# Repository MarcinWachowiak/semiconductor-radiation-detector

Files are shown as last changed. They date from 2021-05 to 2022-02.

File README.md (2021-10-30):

# Semiconductor Radiation Detector
<div align="justify">
Radiation detector based on PIN diode with extensive signal processing. The signal chain consists of multiple stages such as bootstrapped preamplifier, filtering, baseline restorer, sample and hold, and set of comparators detecting slopes of pulses. The signal processing board provides analog output for ADC along with digital signals triggering measurements. <a href="https://hackaday.io/project/159909-gamma-pin-semiconductor-radiation-detector">Hackaday project log</a>

</div>

  - **Manufactured prototypes**
  
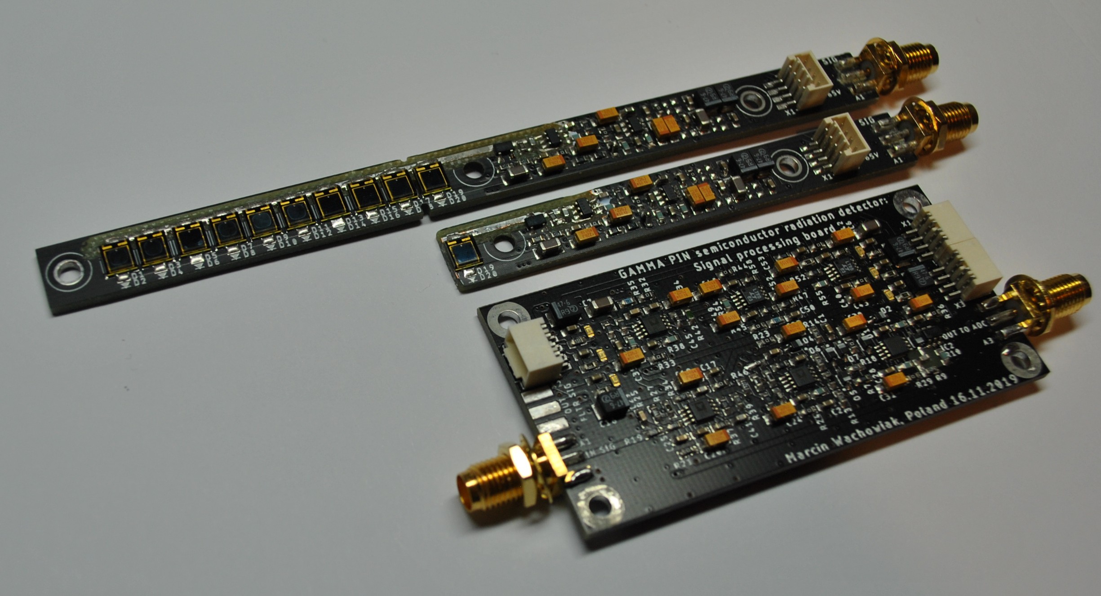
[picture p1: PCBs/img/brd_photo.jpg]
board_photo
    

  - **Preamplifier board**

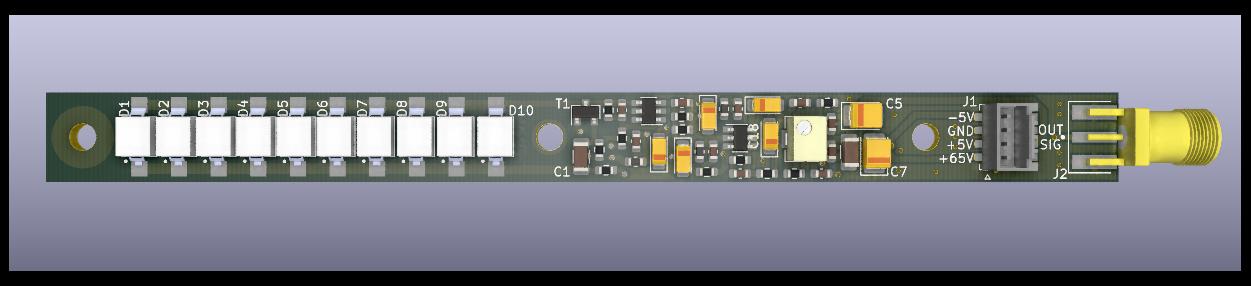
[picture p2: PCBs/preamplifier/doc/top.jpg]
preamplifier_top
    
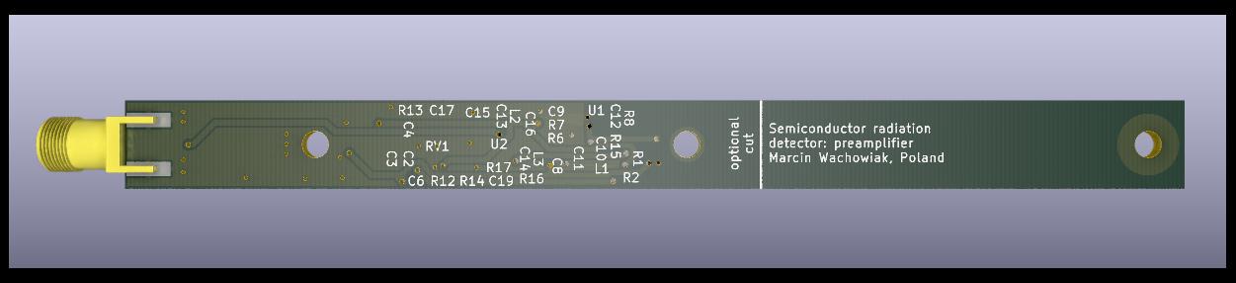
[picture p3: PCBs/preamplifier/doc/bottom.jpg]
preamplifier_bottom
    

  - **Signal processing board**

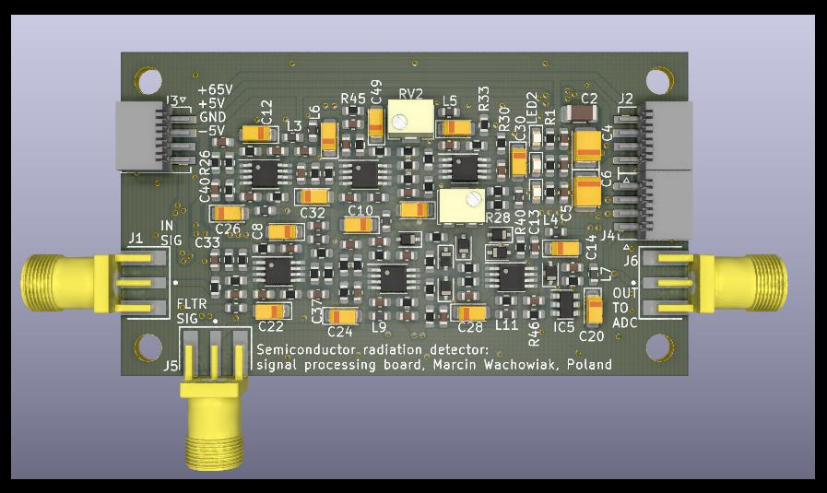
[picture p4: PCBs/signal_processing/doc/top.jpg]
signal_processing_top
    
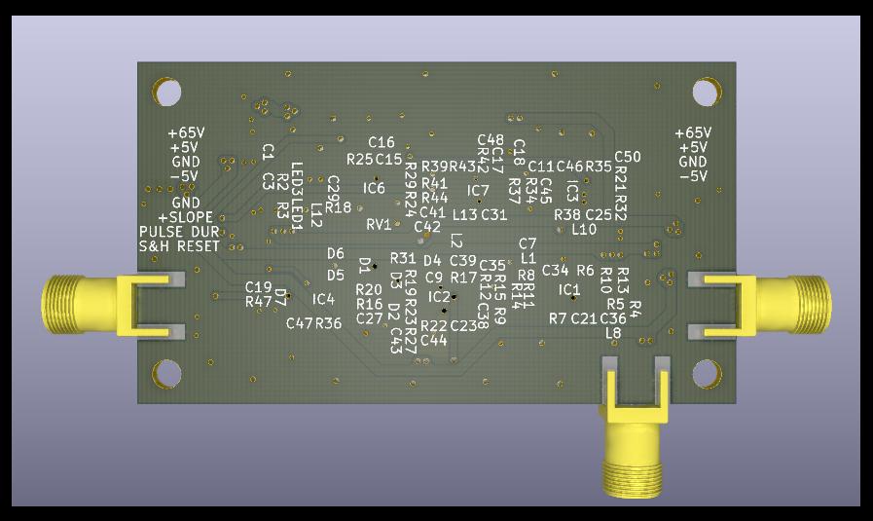
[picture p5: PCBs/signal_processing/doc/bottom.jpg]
signal_processing_bottom


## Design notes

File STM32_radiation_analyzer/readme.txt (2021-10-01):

In case of problems with COM port opening, either use Teraterm instead of Putty or try to modify usb_cdc
according to https://github.com/Ant1882/STM32F429-Tracealyzer-Demo/commit/4cf6591b3bdff098292349874f8c0c8df7802986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
this issue is encountered mostly on Win 10.

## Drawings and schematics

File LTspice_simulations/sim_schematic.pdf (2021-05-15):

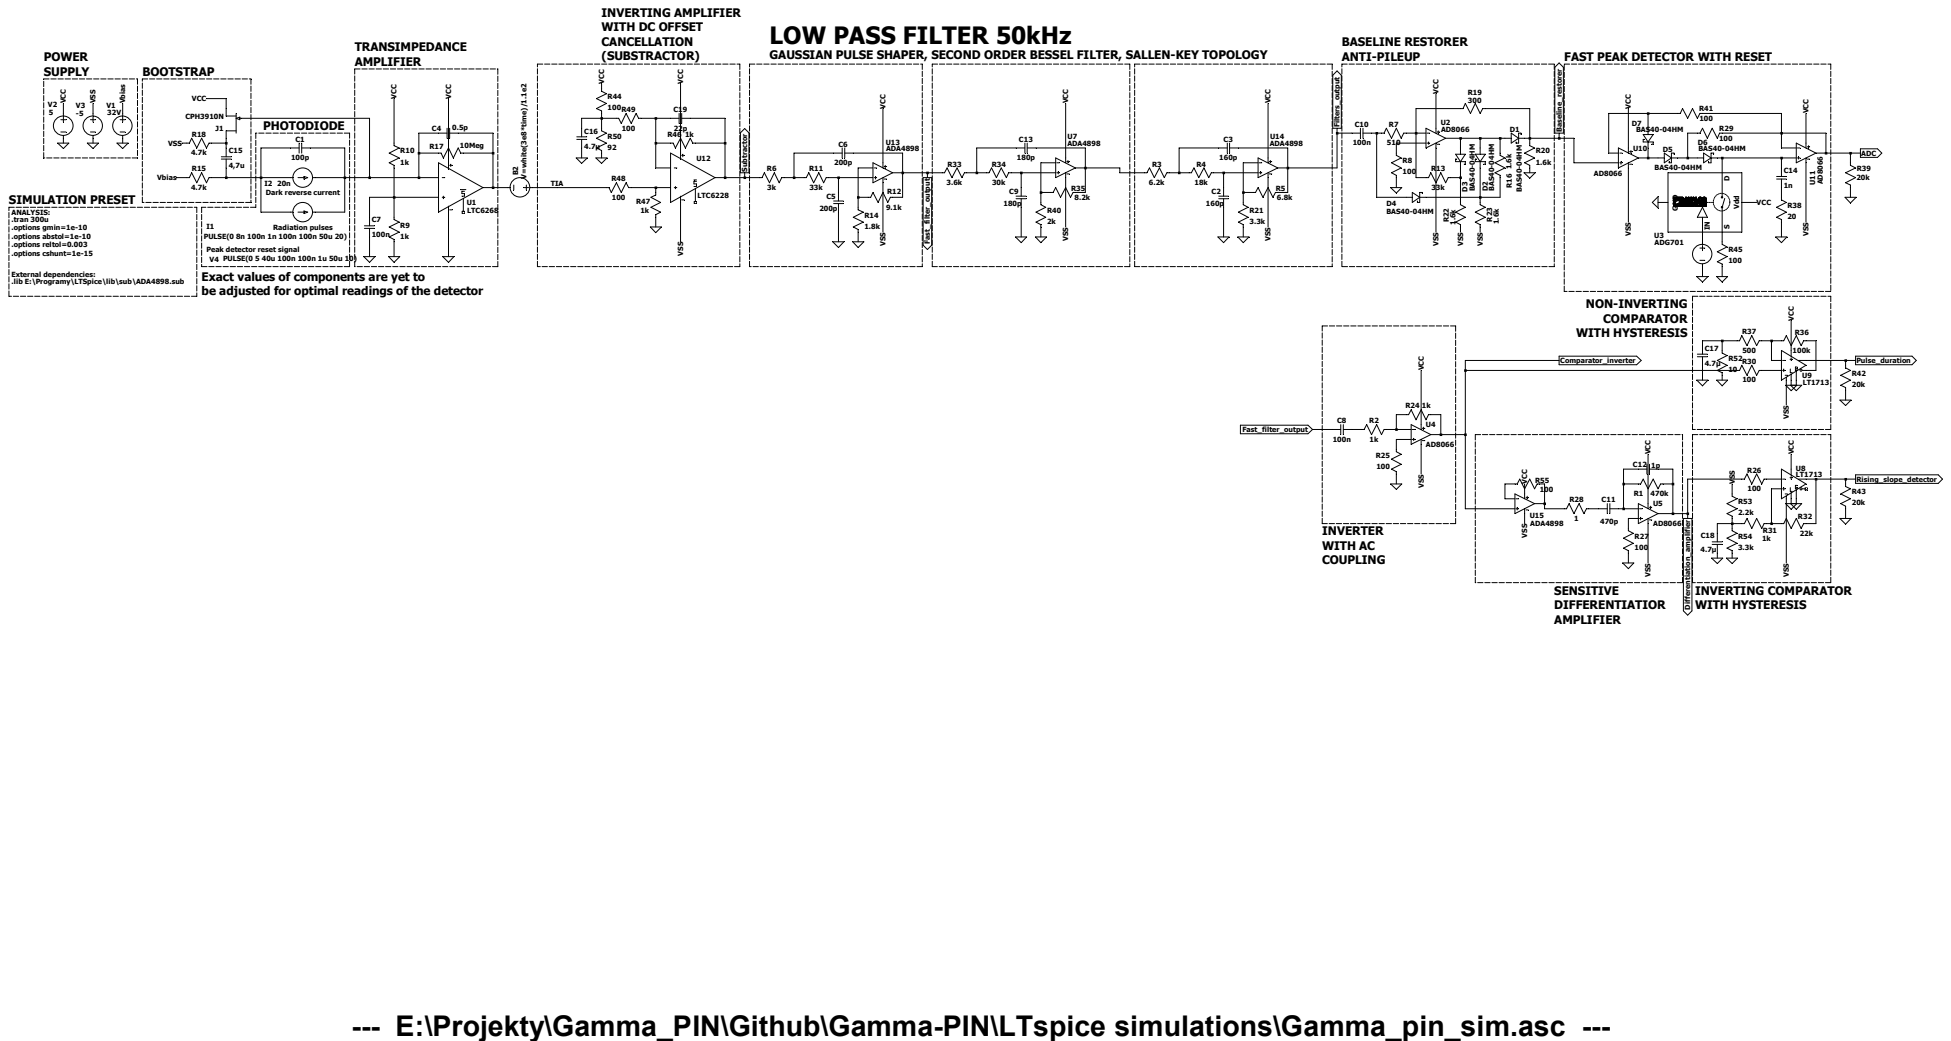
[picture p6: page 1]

LOW PASS FILTER 50kHz
GAUSSIAN PULSE SHAPER, SECOND ORDER BESSEL FILTER, SALLEN-KEY TOPOLOGY

FAST PEAK DETECTOR WITH RESET

PULSE(0 8n 100n 1n 100n 100n 50u 20)
Peak detector reset signal
V4 PULSE(0 5 40u 100n 100n 1u 50u 10)
Exact values of components are yet to
be adjusted for optimal readings of the detector

External dependencies:
.lib E:\Programy\LTSpice\lib\sub\ADA4898.sub

--- E:\Projekty\Gamma_PIN\Github\Gamma-PIN\LTspice simulations\Gamma_pin_sim.asc ---

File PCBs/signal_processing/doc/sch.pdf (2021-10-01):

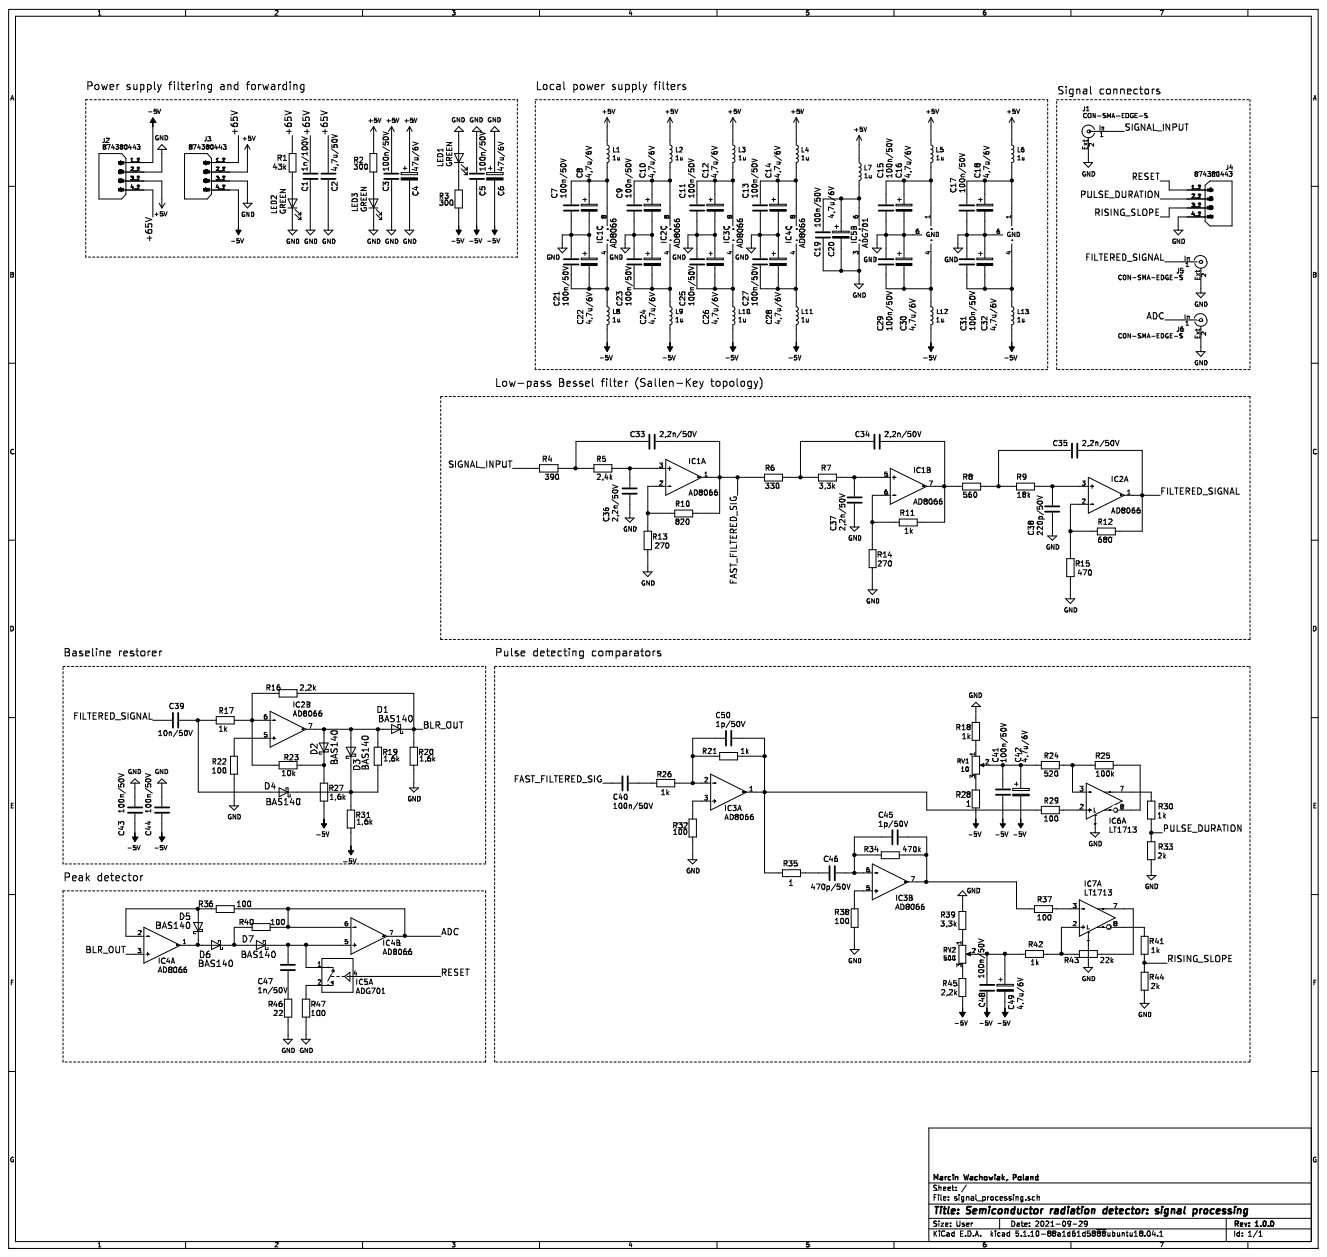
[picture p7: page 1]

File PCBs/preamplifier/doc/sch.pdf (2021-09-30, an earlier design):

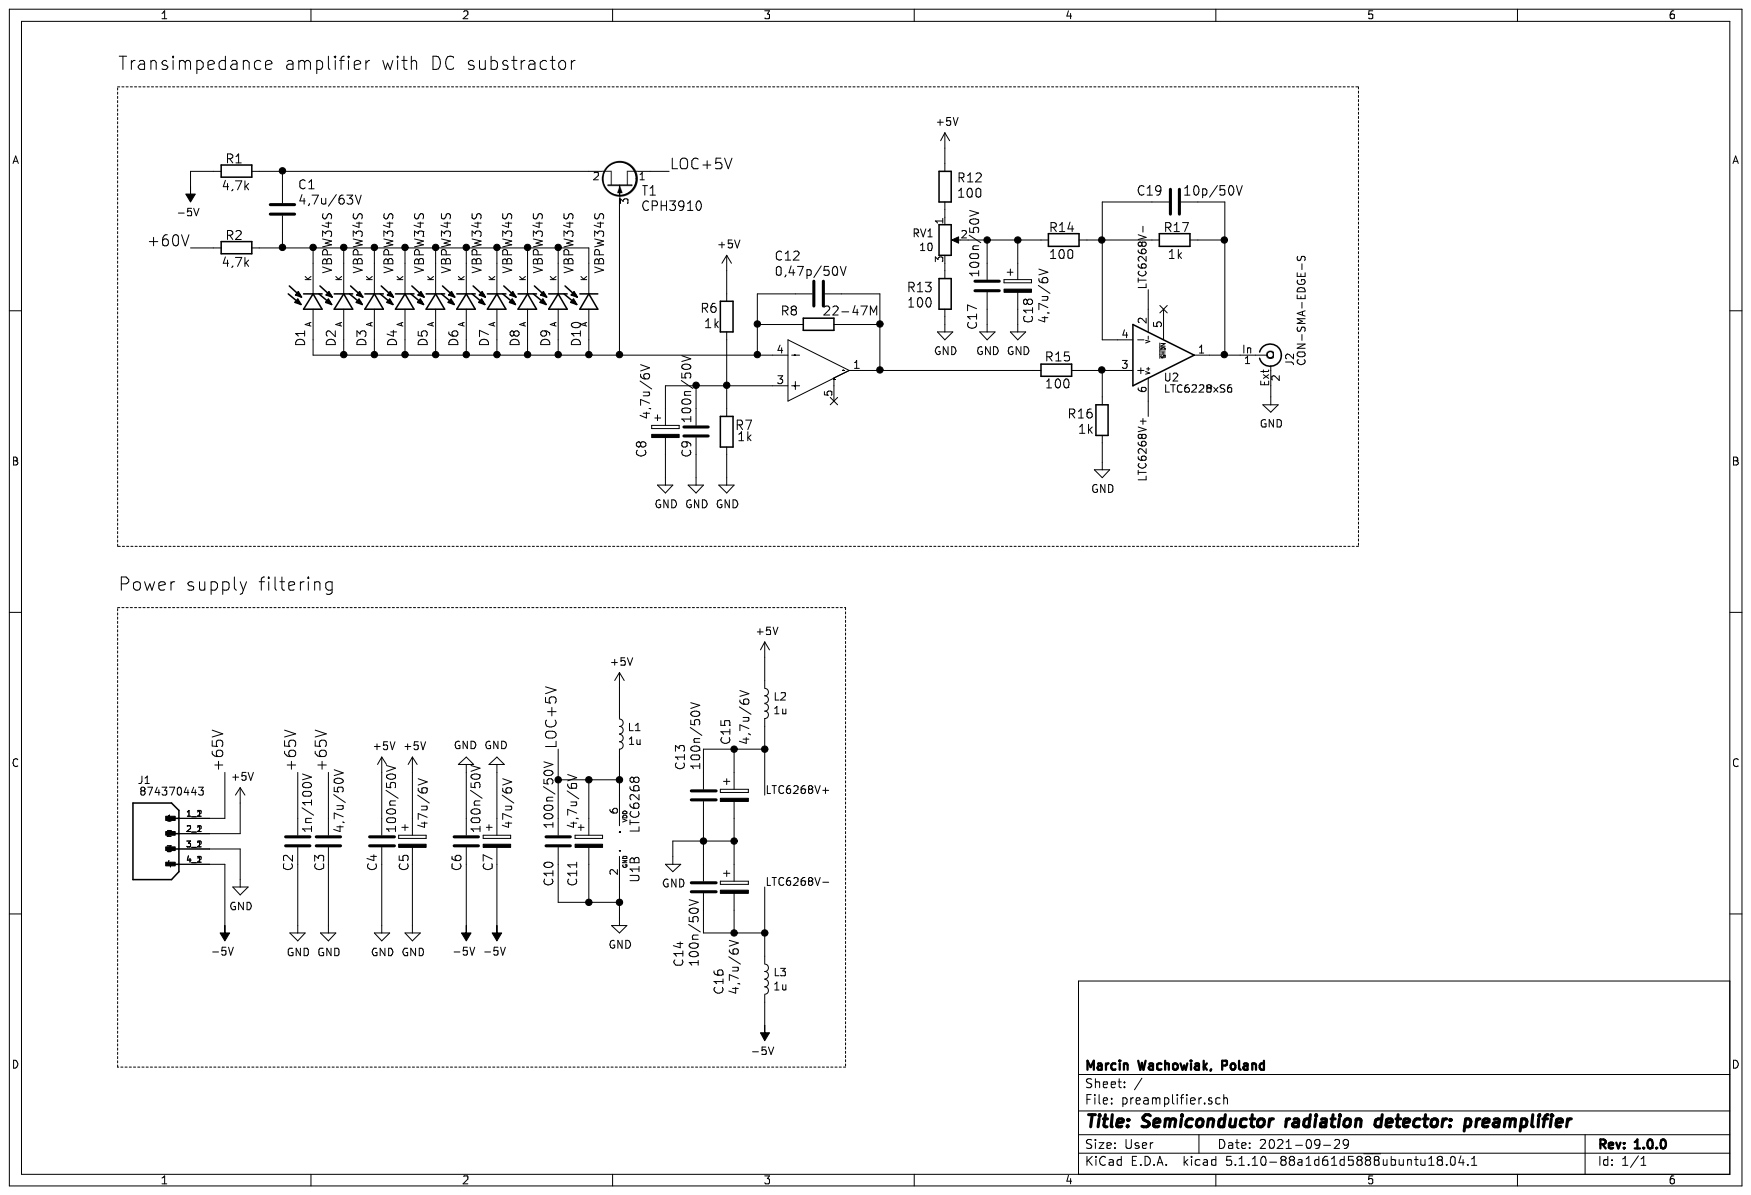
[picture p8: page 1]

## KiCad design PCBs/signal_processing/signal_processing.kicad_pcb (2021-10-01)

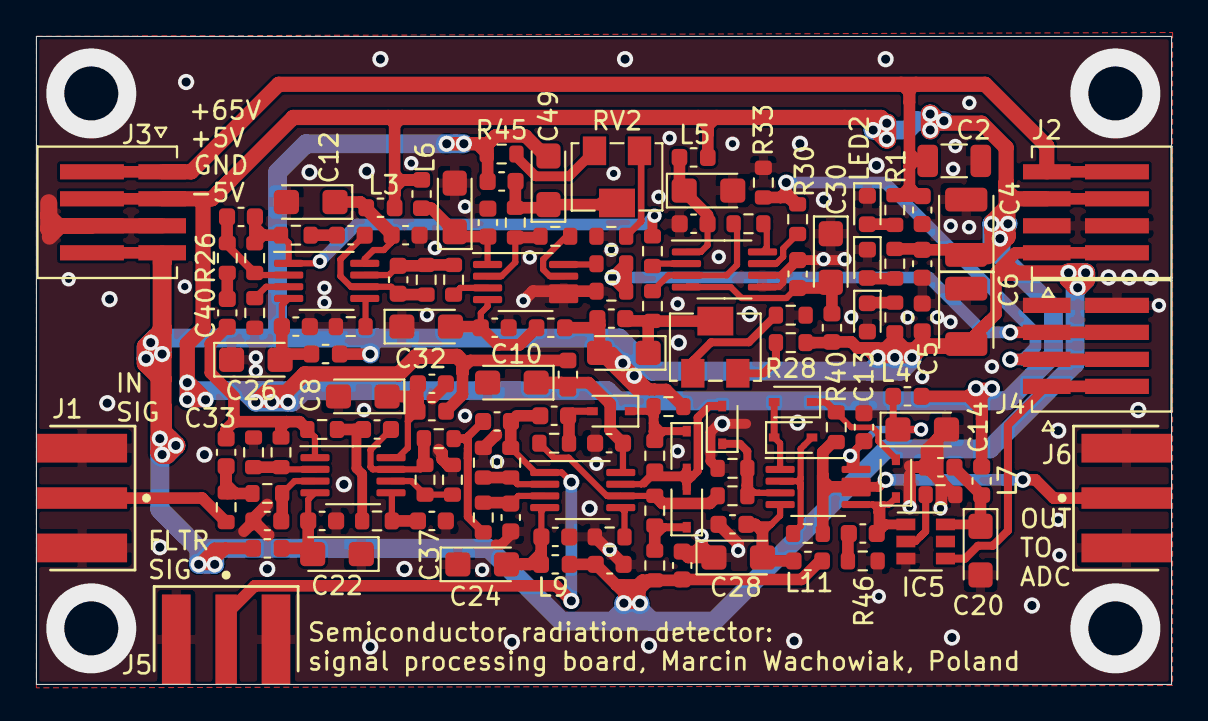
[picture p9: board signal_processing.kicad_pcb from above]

Board: 2 copper layers, 63.1 x 36.0 mm, 135 parts (0 on the bottom side), 72 nets.

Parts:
C1: 1n/100V; C_0603_1608Metric
C2: 4,7u/50V; C_1206_3216Metric
C3, C5, C7, C9, C11, C13, C15, C17, C19, C21, C23, C25, C27, C29, C31, C40, C41, C43, C44, C48: 100n/50V; C_0603_1608Metric
C4, C6: 47u/6V; CP_EIA-3528-21_Kemet-B
C8, C10, C12, C14, C16, C18, C20, C22, C24, C26, C28, C30, C32, C42, C49: 4,7u/6V; CP_EIA-3216-18_Kemet-A
C33, C34, C35, C36, C37: 2,2n/50V; C_0603_1608Metric
C38: 220p/50V; C_0603_1608Metric
C39: 10n/50V; C_0603_1608Metric
C45, C50: 1p/50V; C_0603_1608Metric
C46: 470p/50V; C_0603_1608Metric
C47: 1n/50V; C_0603_1608Metric
D1, D2, D3, D4, D5, D6, D7: BAS140; D_SOD-323
IC1, IC2, IC3, IC4: AD8066; MSOP-8_3x3mm_P0.65mm
IC5: ADG701; SOT-23-6
IC6, IC7: LT1713; MSOP-8_3x3mm_P0.65mm
J1, J5, J6: CON-SMA-EDGE-S
J2, J3, J4: 874380443; 87438-0443
L1, L2, L3, L4, L5, L6, L7, L8, L9, L10, L11, L12, L13: 1u; L_0603_1608Metric
LED1, LED2, LED3: GREEN; LED_0603_1608Metric
R1: 43k; R_0603_1608Metric
R2, R3: 300; R_0603_1608Metric
R4: 390; R_0603_1608Metric
R5: 2,4k; R_0603_1608Metric
R6: 330; R_0603_1608Metric
R7, R39: 3,3k; R_0603_1608Metric
R8: 560; R_0603_1608Metric
R9: 18k; R_0603_1608Metric
R10: 820; R_0603_1608Metric
R11, R17, R18, R21, R26, R30, R41, R42: 1k; R_0603_1608Metric
R12: 680; R_0603_1608Metric
R13, R14: 270; R_0603_1608Metric
R15: 470; R_0603_1608Metric
R16, R45: 2,2k; R_0603_1608Metric
R19, R20, R27, R31: 1,6k; R_0603_1608Metric
R22, R29, R32, R36, R37, R38, R40, R47: 100; R_0603_1608Metric
R23: 10k; R_0603_1608Metric
R24: 520; R_0603_1608Metric
R25: 100k; R_0603_1608Metric
R28, R35: 1; R_0603_1608Metric
R33, R44: 2k; R_0603_1608Metric
R34: 470k; R_0603_1608Metric
R43: 22k; R_0603_1608Metric
R46: 22; R_0603_1608Metric
RV1: 10; Potentiometer_Bourns_3224W_Vertical
RV2: 500; Potentiometer_Bourns_3224W_Vertical

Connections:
+5V: C3.2, C4.1, J2.3_1, J2.3_2, J3.2_1, J3.2_2, L1.1, L2.1, L3.1, L4.1, L5.1, L6.1, L7.1, R2.1
-5V: C5.1, C6.2, C41.2, C42.2, C43.1, C44.1, C48.2, C49.2, J2.1_1, J2.1_2, J3.4_1, J3.4_2, L8.2, L9.2, L10.2, L11.2, L12.2, L13.2, R3.2, R27.1, R28.1, R31.1, R45.1
/+65V: C1.2, C2.1, J2.4_1, J2.4_2, J3.1_1, J3.1_2, R1.1
/ADC: IC4.6, IC4.7, J6.1, R36.1, R40.1
/BLR_OUT: D1.1, IC4.3, R16.2, R20.2
/FAST_FILTERED_SIG: C33.1, C40.2, IC1.1, R6.2, R10.1
/FILTERED_SIGNAL: C35.1, C39.2, IC2.1, J5.1, R12.1
/PULSE_DURATION: J4.2_1, J4.2_2, R30.2, R33.1
/RESET: IC5.4, J4.1_1, J4.1_2
/RISING_SLOPE: J4.3_1, J4.3_2, R41.2, R44.1
/SIGNAL_INPUT: J1.1, R4.2
GND: C1.1, C2.2, C3.1, C4.2, C5.2, C6.1, C7.1, C8.2, C9.1, C10.2, C11.1, C12.2, C13.1, C14.2, C15.1, C16.2, C17.1, C18.2, C19.1, C20.2, C21.2, C22.1, C23.2, C24.1, C25.2, C26.1, C27.2, C28.1, C29.2, C30.1, C31.2, C32.1, C36.1, C37.1, C38.1, C43.2, C44.2, IC5.3, IC6.5, IC6.6, IC7.5, IC7.6, J1.2, J2.2_1, J2.2_2, J3.3_1, J3.3_2, J4.4_1, J4.4_2, J5.2, J6.2, LED1.2, LED2.1, LED3.1, R13.2, R14.2, R15.2, R18.2, R20.1, R22.2, R32.2, R33.2, R38.2, R39.2, R44.2, R46.2, R47.2
unnamed: C7.2, C8.1, IC1.8, L1.2
unnamed: C9.2, C10.1, IC2.8, L2.2
unnamed: C11.2, C12.1, IC3.8, L3.2
unnamed: C13.2, C14.1, IC4.8, L4.2
unnamed: C15.2, C16.1, IC6.1, L5.2
unnamed: C17.2, C18.1, IC7.1, L6.2
unnamed: C19.2, C20.1, IC5.6, L7.2
unnamed: C21.1, C22.2, IC1.4, L8.1
unnamed: C23.1, C24.2, IC2.4, L9.1
unnamed: C25.1, C26.2, IC3.4, L10.1
unnamed: C27.1, C28.2, IC4.4, L11.1
unnamed: C29.1, C30.2, IC6.4, L12.1
unnamed: C31.1, C32.2, IC7.4, L13.1
unnamed: C33.2, R4.1, R5.2
unnamed: C34.1, IC1.7, R8.2, R11.1
unnamed: C34.2, R6.1, R7.2
unnamed: C35.2, R8.1, R9.2
unnamed: C36.2, IC1.3, R5.1
unnamed: C37.2, IC1.5, R7.1
unnamed: C38.2, IC2.3, R9.1
unnamed: C39.1, D4.2, R17.2
unnamed: C40.1, R26.1
unnamed: C41.1, C42.1, R24.2, RV1.2
unnamed: C45.1, IC3.7, R34.1, R37.2
unnamed: C45.2, C46.1, IC3.6, R34.2
unnamed: C46.2, R35.1
unnamed: C47.1, D7.1, IC4.5, IC5.1
unnamed: C47.2, R46.1
unnamed: C48.1, C49.1, R42.2, RV2.2
unnamed: C50.1, IC3.1, R21.1, R29.2, R35.2
unnamed: C50.2, IC3.2, R21.2, R26.2
unnamed: D1.2, D2.2, D3.2, IC2.7, R19.2
unnamed: D2.1, R23.2, R27.2
unnamed: D3.1, D4.1, R19.1, R31.2
unnamed: D5.1, D6.2, IC4.1
unnamed: D5.2, IC4.2, R36.2
unnamed: D6.1, D7.2, R40.2
unnamed: IC1.2, R10.2, R13.1
unnamed: IC1.6, R11.2, R14.1
unnamed: IC2.2, R12.2, R15.1
unnamed: IC2.5, R22.1
unnamed: IC2.6, R16.1, R17.1, R23.1
unnamed: IC3.3, R32.1
unnamed: IC3.5, R38.1
unnamed: IC5.2, R47.1
unnamed: IC6.2, R29.1
unnamed: IC6.3, R24.1, R25.2
unnamed: IC6.7, R30.1
unnamed: IC6.8, R25.1
unnamed: IC7.2, R42.1, R43.2
unnamed: IC7.3, R37.1
unnamed: IC7.7, R43.1
unnamed: IC7.8, R41.1
unnamed: LED1.1, R3.1
unnamed: LED2.2, R1.2
unnamed: LED3.2, R2.2
unnamed: R18.1, RV1.1
unnamed: R28.2, RV1.3
unnamed: R39.1, RV2.1
unnamed: R45.2, RV2.3

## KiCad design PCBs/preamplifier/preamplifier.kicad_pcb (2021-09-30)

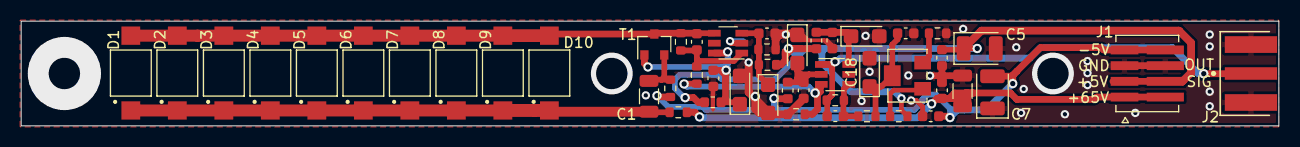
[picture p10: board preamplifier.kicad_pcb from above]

Board: 2 copper layers, 120.2 x 10.0 mm, 49 parts (0 on the bottom side), 18 nets.

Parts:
C1: 4,7u/63V; C_1206_3216Metric
C2: 1n/100V; C_0603_1608Metric
C3: 4,7u/50V; C_1206_3216Metric
C4, C6, C9, C10, C13, C14, C17: 100n/50V; C_0603_1608Metric
C5, C7: 47u/6V; CP_EIA-3528-21_Kemet-B
C8, C11, C15, C16, C18: 4,7u/6V; CP_EIA-3216-18_Kemet-A
C12: 0,47p/50V; C_0603_1608Metric
C19: 10p/50V; C_0603_1608Metric
D1, D2, D3, D4, D5, D6, D7, D8, D9, D10: VBPW34S; XDCR_VBPW34S
J1: 874370443; 87437-0443
J2: CON-SMA-EDGE-S
L1, L2, L3: 1u; L_0603_1608Metric
R1, R2: 4,7k; R_0603_1608Metric
R6, R7, R16, R17: 1k; R_0603_1608Metric
R8: 22-47M; R_0603_1608Metric
R12, R13, R14, R15: 100; R_0603_1608Metric
RV1: 10; Potentiometer_Bourns_3224W_Vertical
T1: CPH3910; SOT-23
U1: LTC6268; TSOT-23-6
U2: LTC6228xS6; TSOT-23-6

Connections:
+5V: C4.2, C5.1, J1.2_1, J1.2_2, L1.1, L2.1, R6.1, R12.1
-5V: C6.1, C7.2, J1.4_1, J1.4_2, L3.2, R1.2
/+60V: C2.2, C3.1, J1.1_1, J1.1_2, R2.2
/LOC+5V: C10.2, C11.1, L1.2, T1.1, U1.6
/LTC6268V+: C13.2, C15.1, L2.2, U2.6
/LTC6268V-: C14.1, C16.2, L3.1, U2.2
GND: C2.1, C3.2, C4.1, C5.2, C6.2, C7.1, C8.2, C9.1, C10.1, C11.2, C13.1, C14.2, C15.2, C16.1, C17.2, C18.2, J1.3_1, J1.3_2, J2.2, R7.2, R13.2, R16.2, U1.2
unnamed: C1.1, D1.K, D2.K, D3.K, D4.K, D5.K, D6.K, D7.K, D8.K, D9.K, D10.K, R2.1
unnamed: C1.2, R1.1, T1.2
unnamed: C8.1, C9.2, R6.2, R7.1, U1.3
unnamed: C12.1, R8.2, R15.1, U1.1
unnamed: C12.2, D1.A, D2.A, D3.A, D4.A, D5.A, D6.A, D7.A, D8.A, D9.A, D10.A, R8.1, T1.3, U1.4
unnamed: C17.1, C18.1, R14.2, RV1.2
unnamed: C19.1, R14.1, R17.2, U2.4
unnamed: C19.2, J2.1, R17.1, U2.1
unnamed: R12.2, RV1.1
unnamed: R13.1, RV1.3
unnamed: R15.2, R16.1, U2.3

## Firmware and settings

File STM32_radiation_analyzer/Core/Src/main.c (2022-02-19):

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
/* Includes ------------------------------------------------------------------*/
#include "main.h"
#include "string.h"
#include "usb_device.h"

/* USER CODE BEGIN Includes */
#include "usbd_cdc_if.h"
#include "string.h"
/* USER CODE END Includes */

/* USER CODE BEGIN PD */

//number of ADC samples to average (16bit samples to save)
#define ADC_BUF_LEN 10

/* USER CODE END PD */

#if defined ( __ICCARM__ ) /*!< IAR Compiler */

#pragma location=0x30040000
ETH_DMADescTypeDef  DMARxDscrTab[ETH_RX_DESC_CNT]; /* Ethernet Rx DMA Descriptors */
#pragma location=0x30040060
ETH_DMADescTypeDef  DMATxDscrTab[ETH_TX_DESC_CNT]; /* Ethernet Tx DMA Descriptors */
#pragma location=0x300400c0
uint8_t Rx_Buff[ETH_RX_DESC_CNT][ETH_MAX_PACKET_SIZE]; /* Ethernet Receive Buffers */

#elif defined ( __CC_ARM )  /* MDK ARM Compiler */

__attribute__((at(0x30040000))) ETH_DMADescTypeDef  DMARxDscrTab[ETH_RX_DESC_CNT]; /* Ethernet Rx DMA Descriptors */
__attribute__((at(0x30040060))) ETH_DMADescTypeDef  DMATxDscrTab[ETH_TX_DESC_CNT]; /* Ethernet Tx DMA Descriptors */
__attribute__((at(0x300400c0))) uint8_t Rx_Buff[ETH_RX_DESC_CNT][ETH_MAX_PACKET_SIZE]; /* Ethernet Receive Buffer */

#elif defined ( __GNUC__ ) /* GNU Compiler */

ETH_DMADescTypeDef DMARxDscrTab[ETH_RX_DESC_CNT] __attribute__((section(".RxDecripSection"))); /* Ethernet Rx DMA Descriptors */
ETH_DMADescTypeDef DMATxDscrTab[ETH_TX_DESC_CNT] __attribute__((section(".TxDecripSection")));   /* Ethernet Tx DMA Descriptors */
uint8_t Rx_Buff[ETH_RX_DESC_CNT][ETH_MAX_PACKET_SIZE] __attribute__((section(".RxArraySection"))); /* Ethernet Receive Buffers */

#endif

ETH_TxPacketConfig TxConfig;
ADC_HandleTypeDef hadc1;
DMA_HandleTypeDef hdma_adc1;

ETH_HandleTypeDef heth;

RTC_HandleTypeDef hrtc;

TIM_HandleTypeDef htim16;

void SystemClock_Config(void);
static void MX_GPIO_Init(void);
static void MX_DMA_Init(void);
static void MX_ETH_Init(void);
static void MX_ADC1_Init(void);
static void MX_TIM16_Init(void);
static void MX_RTC_Init(void);
/* USER CODE BEGIN 0 */
static uint16_t adc_dma_buf [ADC_BUF_LEN];
static uint16_t pulse_ampl_cnt_arr [4096] = {0};
static uint32_t pulse_cnt = 0;

static uint32_t time_cnt = 0;
static uint32_t rising_slope_cnt = 0;

uint8_t conv_cplt = 0;

/* USER CODE END 0 */

/**
  * @brief  The application entry point.
  * @retval int
  */
int main(void)
{
  /* MCU Configuration--------------------------------------------------------*/

  /* Reset of all peripherals, Initializes the Flash interface and the Systick. */
  HAL_Init();

  /* Configure the system clock */
  SystemClock_Config();

  /* Initialize all configured peripherals */
  MX_GPIO_Init();
  MX_DMA_Init();
  MX_ETH_Init();
  MX_ADC1_Init();
  MX_TIM16_Init();
  MX_RTC_Init();
  MX_USB_DEVICE_Init();
  /* USER CODE BEGIN 2 */

  //Start timer
  HAL_TIM_Base_Start_IT(&htim16);

  //ADC calibration
  if(HAL_OK != HAL_ADCEx_Calibration_Start(&hadc1,ADC_CALIB_OFFSET_LINEARITY,ADC_SINGLE_ENDED) && HAL_ADCEx_Calibration_Start(&hadc1,ADC_CALIB_OFFSET,ADC_SINGLE_ENDED)){
	  Error_Handler();
  }

  //start ADC DMA
  if(HAL_OK != HAL_ADC_Start_DMA(&hadc1, (uint32_t*)adc_dma_buf, ADC_BUF_LEN)){
	  Error_Handler();
  }

  // Initialize spectral array to zeros
  memset(pulse_ampl_cnt_arr, 0, sizeof(pulse_ampl_cnt_arr));

  //init message
  HAL_Delay(1000);
  uint8_t buffer[] = "Radiation Analyzer init!\r\n";
  CDC_Transmit_FS(buffer, sizeof(buffer));
  /* USER CODE END 2 */

  /* Infinite loop */
  /* USER CODE BEGIN WHILE */
  while (1)
  {
	    // simple led signal that program is working
		HAL_GPIO_WritePin(GPIOB, GPIO_PIN_14, SET);
		HAL_Delay(1000);
	    //
	    // INTERRUPTS ARE NOT A GOOD PLACE TO DO SEND DATA OR PRINT!
	    //
		HAL_GPIO_WritePin(GPIOB, GPIO_PIN_14, RESET);
		HAL_Delay(1000);
		//GPIOC->ODR = 1 << 3;
		//GPIOC->ODR = 0;

		// TODO add collected data printing to UART
		//	uint8_t buffer2[128];
		//	sprintf(buffer2, "ADC: %d %d %d %d %d %d %d %d %d %d\n\r", adc_dma_buf[0],adc_dma_buf[1],adc_dma_buf[2],adc_dma_buf[3],adc_dma_buf[4],adc_dma_buf[5],adc_dma_buf[6],adc_dma_buf[7],adc_dma_buf[8],adc_dma_buf[9]);
		//	CDC_Transmit_FS(buffer2, sizeof(buffer2));

    /* USER CODE END WHILE */

    /* USER CODE BEGIN 3 */
  }
  /* USER CODE END 3 */
}

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
/* USER CODE BEGIN 4 */

void HAL_TIM_PeriodElapsedCallback(TIM_HandleTypeDef *htim)
{
	if(htim == &htim16){
		  HAL_GPIO_TogglePin(GPIOB, GPIO_PIN_7);
		  time_cnt++;
		  static uint8_t sec_buffer[] = "One second elapsed!\r\n";
		  CDC_Transmit_FS(sec_buffer, sizeof(sec_buffer));
		  if(time_cnt%60 == 0) {
			    static uint8_t min_buffer[] = "One minute elapsed!\r\n";
			    CDC_Transmit_FS(min_buffer, sizeof(min_buffer));
		  	  }
	}
}

//ADC DMA CONVERSION COMPLETE INTERRUPT
void HAL_ADC_ConvCpltCallback(ADC_HandleTypeDef* hadc)
{
	conv_cplt = 1;

	// average collected samples
	uint32_t tmp_sum = 0;
	for (uint8_t i = 0; i < ADC_BUF_LEN; ++i) {
		tmp_sum += adc_dma_buf[i];
	    }
	uint16_t avg_sample_val =(uint16_t) (tmp_sum / ADC_BUF_LEN);

	// increment index corresponding to registered amplitude
	pulse_ampl_cnt_arr[avg_sample_val]++;

	// increment pulse count
	pulse_cnt++;

	//reset S&H block
	HAL_GPIO_WritePin(GPIOE, GPIO_PIN_13, SET);
}

//Interrupt handler
void HAL_GPIO_EXTI_Callback(uint16_t GPIO_Pin){

	if(GPIO_Pin == GPIO_PIN_9){
		//pulse duration - rising
		//enable S&H block - peak capture
		HAL_GPIO_WritePin(GPIOE, GPIO_PIN_13, RESET);

	} else if (GPIO_Pin == GPIO_PIN_14){
		//pulse duration falling
		//pulse has reached the peak
		//trigger ADC sampling burst
		SET_BIT(ADC1->CR, ADC_CR_ADSTART);

	} else if (GPIO_Pin == GPIO_PIN_15){
		//rising slope trigger detected
		// TODO: Add detection of pulse overlapping
		// Multiple rising slope triggers during single pulse period - overlapping pulse - discard
		rising_slope_cnt++;

	} else {
		//Unhandled interrupt - exception
	    Error_Handler();
	}

}
/* USER CODE END 4 */
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


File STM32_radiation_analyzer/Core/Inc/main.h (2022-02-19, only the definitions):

#define MCO_Pin GPIO_PIN_0
#define MCO_GPIO_Port GPIOH
#define RMII_MDC_Pin GPIO_PIN_1
#define RMII_MDC_GPIO_Port GPIOC
#define RMII_REF_CLK_Pin GPIO_PIN_1
#define RMII_REF_CLK_GPIO_Port GPIOA
#define RMII_MDIO_Pin GPIO_PIN_2
#define RMII_MDIO_GPIO_Port GPIOA
#define analog_in_Pin GPIO_PIN_3
#define analog_in_GPIO_Port GPIOA
#define RMII_CRS_DV_Pin GPIO_PIN_7
#define RMII_CRS_DV_GPIO_Port GPIOA
#define RMII_RXD0_Pin GPIO_PIN_4
#define RMII_RXD0_GPIO_Port GPIOC
#define RMII_RXD1_Pin GPIO_PIN_5
#define RMII_RXD1_GPIO_Port GPIOC
#define rising_edge_trigger_Pin GPIO_PIN_15
#define rising_edge_trigger_GPIO_Port GPIOF
#define rising_edge_trigger_EXTI_IRQn EXTI15_10_IRQn
#define sample_and_hold_reset_Pin GPIO_PIN_13
#define sample_and_hold_reset_GPIO_Port GPIOE
#define RMII_TXD1_Pin GPIO_PIN_13
#define RMII_TXD1_GPIO_Port GPIOB
#define LD3_Pin GPIO_PIN_14
#define LD3_GPIO_Port GPIOB
#define USB_PowerSwitchOn_Pin GPIO_PIN_6
#define USB_PowerSwitchOn_GPIO_Port GPIOG
#define USB_OverCurrent_Pin GPIO_PIN_7
#define USB_OverCurrent_GPIO_Port GPIOG
#define USB_SOF_Pin GPIO_PIN_8
#define USB_SOF_GPIO_Port GPIOA
#define USB_VBUS_Pin GPIO_PIN_9
#define USB_VBUS_GPIO_Port GPIOA
#define USB_ID_Pin GPIO_PIN_10
#define USB_ID_GPIO_Port GPIOA
#define pulse_dur_rising_Pin GPIO_PIN_9
#define pulse_dur_rising_GPIO_Port GPIOG
#define pulse_dur_rising_EXTI_IRQn EXTI9_5_IRQn
#define RMII_TX_EN_Pin GPIO_PIN_11
#define RMII_TX_EN_GPIO_Port GPIOG
#define RMII_TXD0_Pin GPIO_PIN_13
#define RMII_TXD0_GPIO_Port GPIOG
#define pulse_dur_falling_Pin GPIO_PIN_14
#define pulse_dur_falling_GPIO_Port GPIOG
#define pulse_dur_falling_EXTI_IRQn EXTI15_10_IRQn
#define LD2_Pin GPIO_PIN_7
#define LD2_GPIO_Port GPIOB

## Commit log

2021-09-29 Reorganization of pcb files
    [preamplifier.kicad_pcb, preamplifier.sch, signal_processing.kicad_pcb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]
2021-09-30 finished preamplifier board redesigning
    [preamplifier-B_Mask.gbs, preamplifier-B_Paste.gbp, preamplifier-B_SilkS.gbo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]
2021-09-30 sp board update
    [signal_processing.kicad_pcb, signal_processing.sch]
2021-10-01 Init STM32 experimental code
2021-10-01 finished pcbs
    [signal_processing-B_Mask.gbs, signal_processing-B_Paste.gbp, signal_processing-B_SilkS.gbo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]
2022-02-19 Updated code and solved CDC transmit issue
    [RadiationAnalyzer.ioc, main.c, main.h]

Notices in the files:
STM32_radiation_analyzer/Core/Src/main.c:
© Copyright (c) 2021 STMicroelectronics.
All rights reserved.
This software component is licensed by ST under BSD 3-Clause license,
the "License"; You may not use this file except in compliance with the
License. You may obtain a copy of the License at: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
